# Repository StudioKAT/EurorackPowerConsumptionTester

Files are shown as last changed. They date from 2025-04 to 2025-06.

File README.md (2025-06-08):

# Eurorack Power Consumption Tester
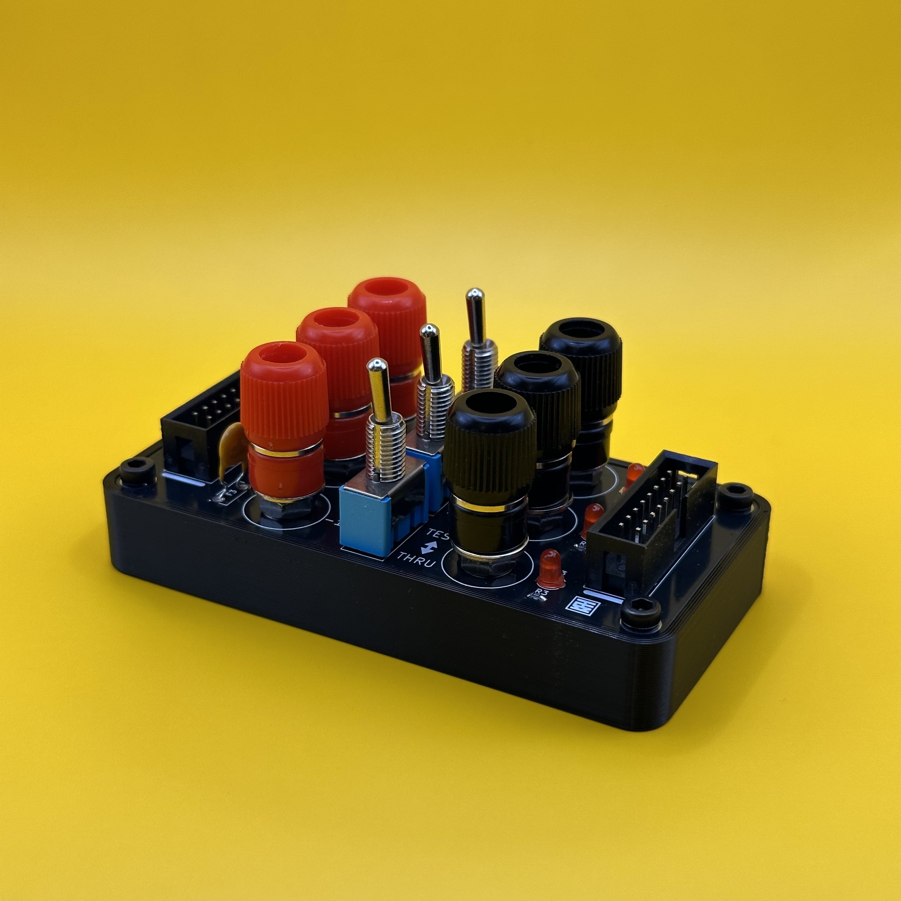
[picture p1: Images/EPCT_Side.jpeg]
Overview


## 概要 / Overview

**Eurorack Power Consumption Tester** は、モジュラーシンセサイザーの消費電力を測定するための治具です。  
デジタルマルチメーター（テスター）と組み合わせて使用し、+5V、+12V、-12Vの各電源レールにおける消費電流の測定が可能です。

**Eurorack Power Consumption Tester** is a utility jig for measuring the power consumption of modular synthesizers.  
Used in combination with a digital multimeter, it allows measurement of current draw on +5V, +12V, and -12V rails.

## 仕様 / Spec
- Format: External testing tool (not a rack-mounted module)  
- Function: Power Consumption Tester Jig
- Current needs: +12V: 0mA, -12V: 0mA (Passive)
- Width: 0 HP
- Depth: 10mm

## 販売 / Sales

現在販売予定はありません。

## ライセンス / License

この作品は [Creative Commons 表示 - 継承 4.0 国際 (CC BY-SA 4.0)](https://creativecommons.org/licenses/by-sa/4.0/deed.ja) の下でライセンスされています。  
This work is licensed under the [Creative Commons Attribution-ShareAlike 4.0 International License](https://creativecommons.org/licenses/by-sa/4.0/).

## クレジット / Credits

- Designed by : StudioKAT
- Website : https://www.studiokat.jp/
- GitHub : https://github.com/StudioKAT
- X(Twitter) : https://x.com/StudioKAT_synth
- Instagram : https://www.instagram.com/studiokat_modular/

## 更新履歴 / Changelog

- `2025-04-24` v1.0 Released version 1.0

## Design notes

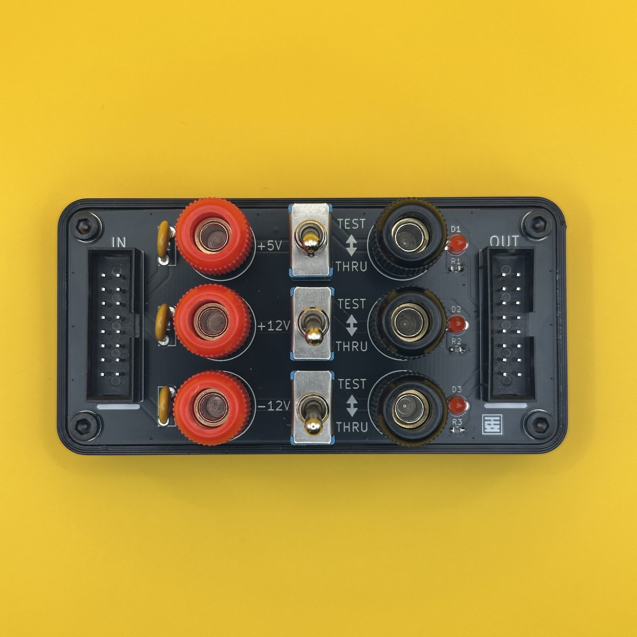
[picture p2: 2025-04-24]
Images/EPCT_Top.jpeg

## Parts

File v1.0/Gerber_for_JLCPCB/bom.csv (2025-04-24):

Designator | Footprint | Quantity | Value | LCSC Part #
D1, D2, D3 | LED_D3.0mm | 3 | LED
F1, F2, F3 | Fuse_Bourns_MF-RG300 | 3 | MF-R050
J1 | BoxHeader_2x08_2.54mm_Europower | 1 | IN
J2 | BoxHeader_2x08_2.54mm_Europower | 1 | OUT
R1 | 0603 | 1 | 1K
R2, R3 | 0603 | 2 | 2.2K
SW1, SW2, SW3 | SPDT | 3 | SW_SPDT

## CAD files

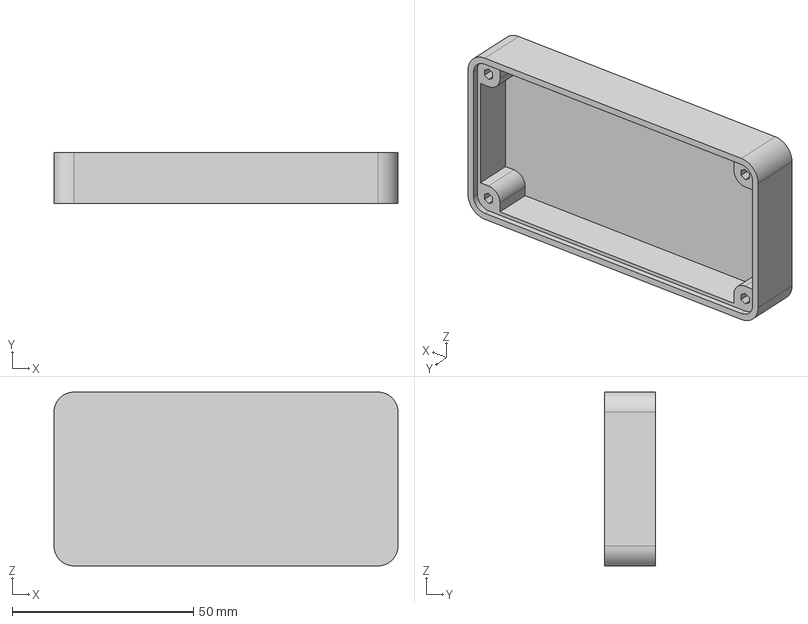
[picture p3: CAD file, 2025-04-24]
v1.0/3DPrint/Eurorack Power Consumption Tester Holder v2.step
95.0 x 14.2 x 48.0 mm

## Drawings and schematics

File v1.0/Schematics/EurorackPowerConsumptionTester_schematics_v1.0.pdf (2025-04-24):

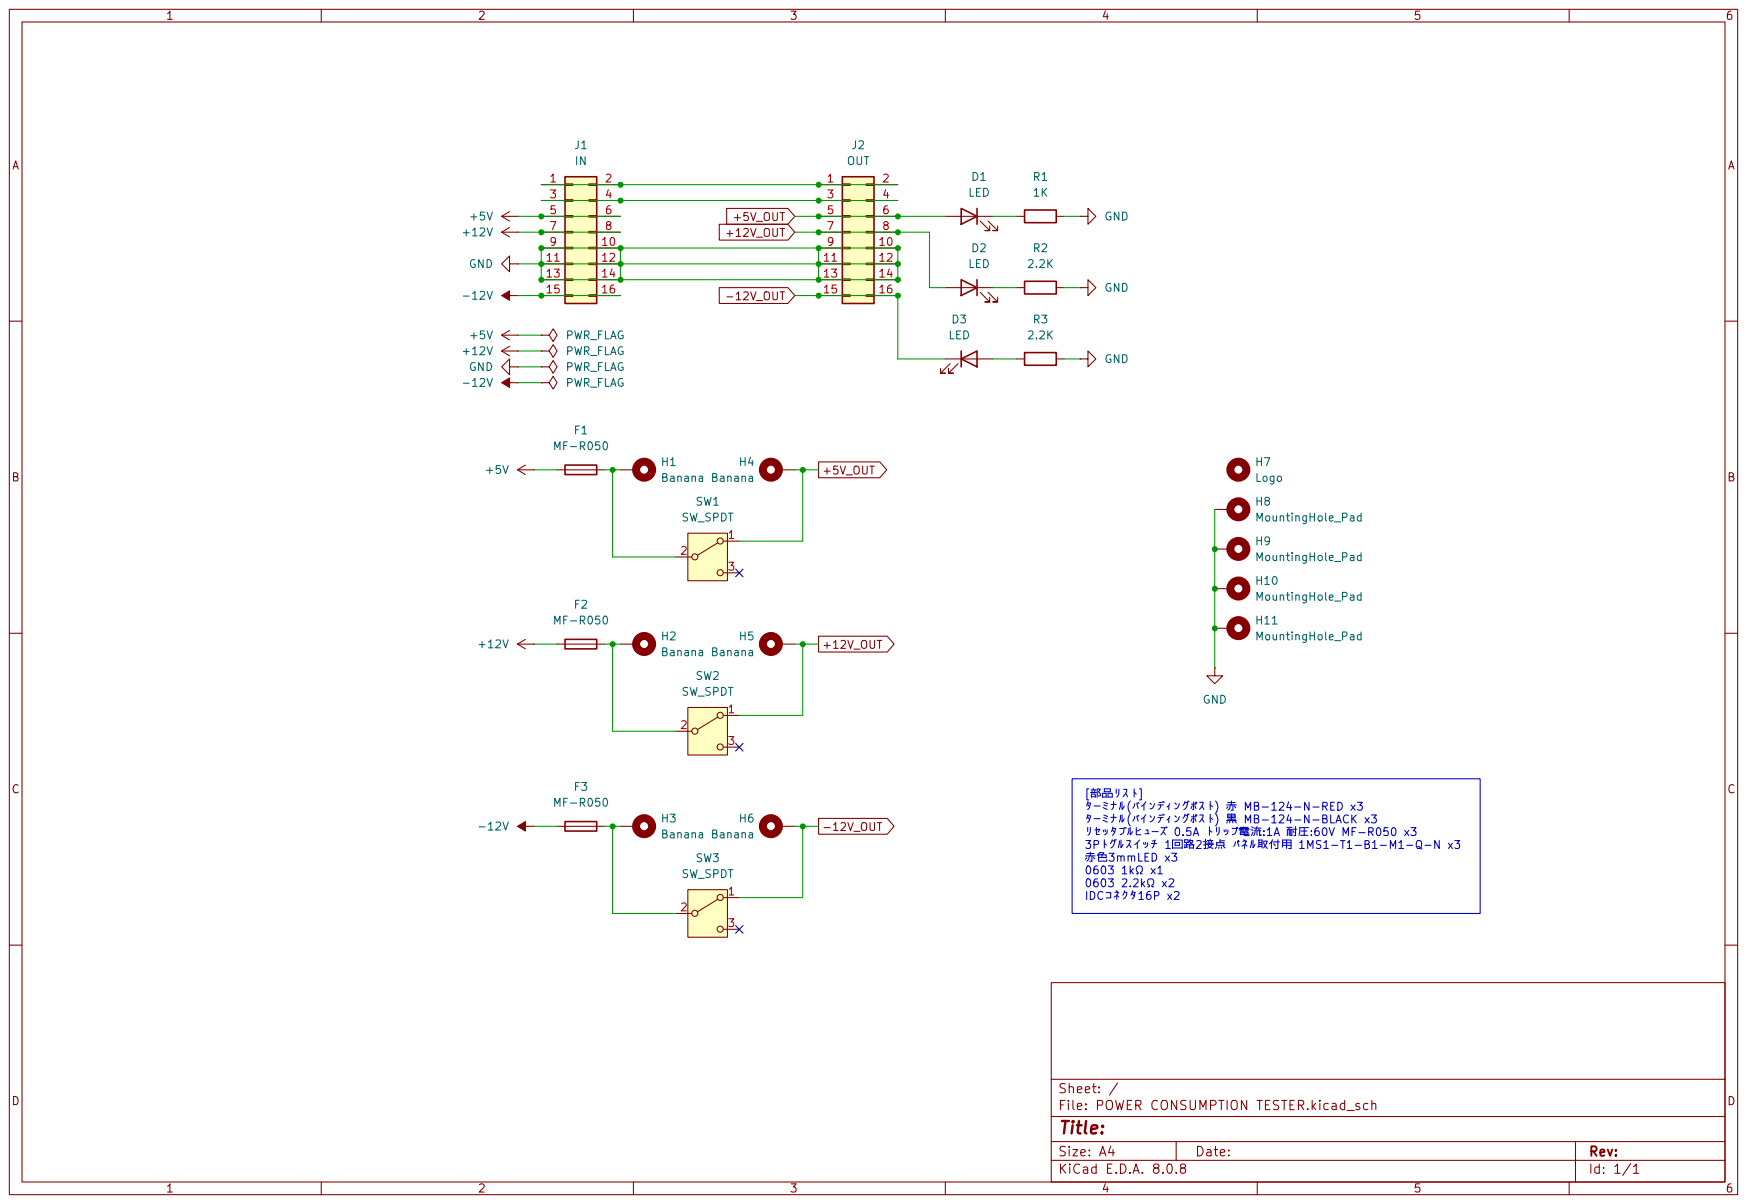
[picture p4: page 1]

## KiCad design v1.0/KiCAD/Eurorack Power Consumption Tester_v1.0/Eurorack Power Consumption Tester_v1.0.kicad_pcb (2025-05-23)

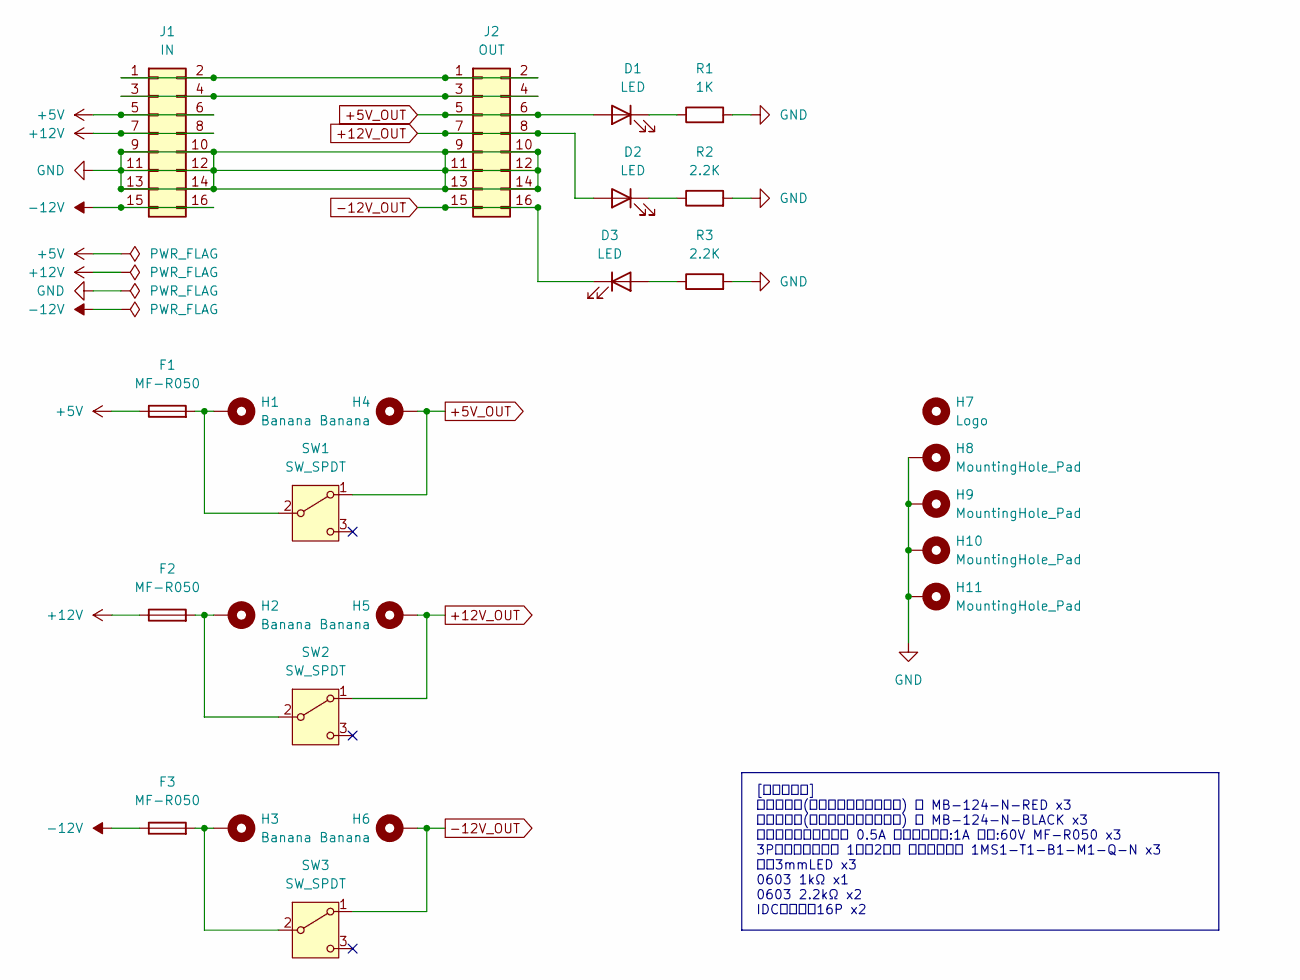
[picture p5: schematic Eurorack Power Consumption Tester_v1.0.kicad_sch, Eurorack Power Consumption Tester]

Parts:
D1, D2, D3: LED; LED_D3.0mm
F1, F2, F3: MF-R050; Fuse_Bourns_MF-RG300
H1, H2, H3, H4, H5, H6: Banana; MountingHole_4.3mm_M4_DIN965_Pad
H7: Logo; StudioKAT_logo
H8, H9, H10, H11: MountingHole_Pad; MountingHole_3.2mm_M3_DIN965_Pad
J1: IN; BoxHeader_2x08_2.54mm_Europower
J2: OUT; BoxHeader_2x08_2.54mm_Europower
R1: 1K; R_0603_1608Metric_Pad0.98x0.95mm_HandSolder
R2, R3: 2.2K; R_0603_1608Metric_Pad0.98x0.95mm_HandSolder
SW1, SW2, SW3: SW_SPDT; SPDT

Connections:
+5V: F1.1, J1.5, J1.6
+5V_OUT: D1.2 (A), H4.1, J2.5, J2.6, SW1.1 (A)
+12V: F2.1, J1.7, J1.8
+12V_OUT: D2.2 (A), H5.1, J2.7, J2.8, SW2.1 (A)
-12V: F3.1, J1.15, J1.16
-12V_OUT: D3.1 (K), H6.1, J2.15, J2.16, SW3.1 (A)
GND: H8.1, H9.1, H10.1, H11.1, J1.9, J1.10, J1.11, J1.12, J1.13, J1.14, J2.9, J2.10, J2.11, J2.12, J2.13, J2.14, R1.2, R2.2, R3.2
unnamed: D1.1 (K), R1.1
unnamed: D2.1 (K), R2.1
unnamed: D3.2 (A), R3.1
unnamed: J1.1, J1.2, J2.1, J2.2
unnamed: J1.3, J1.4, J2.3, J2.4
unnamed: F1.2, H1.1, SW1.2 (B)
unnamed: F2.2, H2.1, SW2.2 (B)
unnamed: F3.2, H3.1, SW3.2 (B)

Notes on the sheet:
[部品リスト] ターミナル(バインディングポスト) 赤 MB-124-N-RED x3 ターミナル(バインディングポスト) 黒 MB-124-N-BLACK x3 リセッタブルヒューズ 0.5A トリップ電流:1A 耐圧:60V MF-R050 x3 3Pトグルスイッチ 1回路2接点 パネル取付用 1MS1-T1-B1-M1-Q-N x3 赤色3mmLED x3 0603 1kΩ x1 0603 2.2kΩ x2 IDCコネクタ16P x2

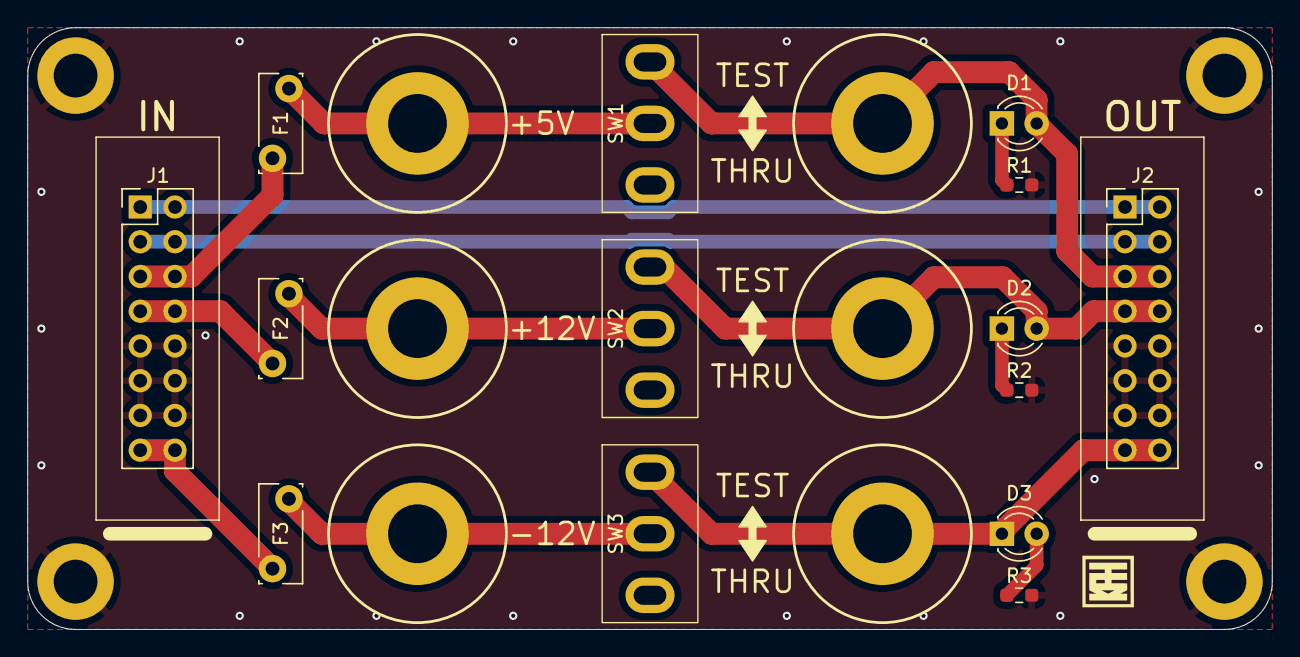
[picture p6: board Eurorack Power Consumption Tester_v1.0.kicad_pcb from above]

Board: 2 copper layers, 91.0 x 44.0 mm, 25 parts (0 on the bottom side), 15 nets.

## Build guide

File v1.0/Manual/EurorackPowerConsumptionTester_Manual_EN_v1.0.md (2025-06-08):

# Eurorack Power Consumption Tester Manual (English)
EPCT_Image

## Overview

**Eurorack Power Consumption Tester** is a utility jig for measuring the power consumption of modular synthesizers.  
Used in combination with a digital multimeter, it allows measurement of current draw on +5V, +12V, and -12V rails.

---

## Specifications

- **Format**: External testing tool (not a rack-mounted module)  
- **Width**: 0 HP  
- **Depth**: 10 mm  
- **Power Draw**: +12V: 0mA / -12V: 0mA (Passive)

---

## Parts List

- [Red Binding Post MB-124-N-RED](https://akizukidenshi.com/catalog/g/g114241/) ×3  
- [Black Binding Post MB-124-N-BLACK](https://akizukidenshi.com/catalog/g/g114242) ×3  
- [Resettable Fuse 0.5A (trip: 1A, 60V) MF-R050](https://akizukidenshi.com/catalog/g/g112628/) ×3  
- [3P Toggle Switch (SPDT) for panel mount](https://akizukidenshi.com/catalog/g/g103774/) ×3  
- [3mm Red LED OSR5JA3Z74A (625nm, 70°)](https://akizukidenshi.com/catalog/g/g111577/) ×3  
- [IDC Box Header 16P (2×8)](https://ja.aliexpress.com/item/1005004266492521.html) ×2  
- Chip Resistor 0603 1kΩ ×1  
- Chip Resistor 0603 2.2kΩ ×2

### Additional Required Tools

- Banana cables ×2  
- Digital multimeter ×1  
- 16P-16P IDC flat cable ×1  
- 16P-10P IDC flat cable ×1

---

## Assembly Tips

- Start with low-profile components (e.g., resistors).  
- The square pad of the LED indicates the cathode (negative).  
- When tightening the binding post nut, be careful not to scratch the solder mask, as this could short to GND.

---

## Usage Instructions

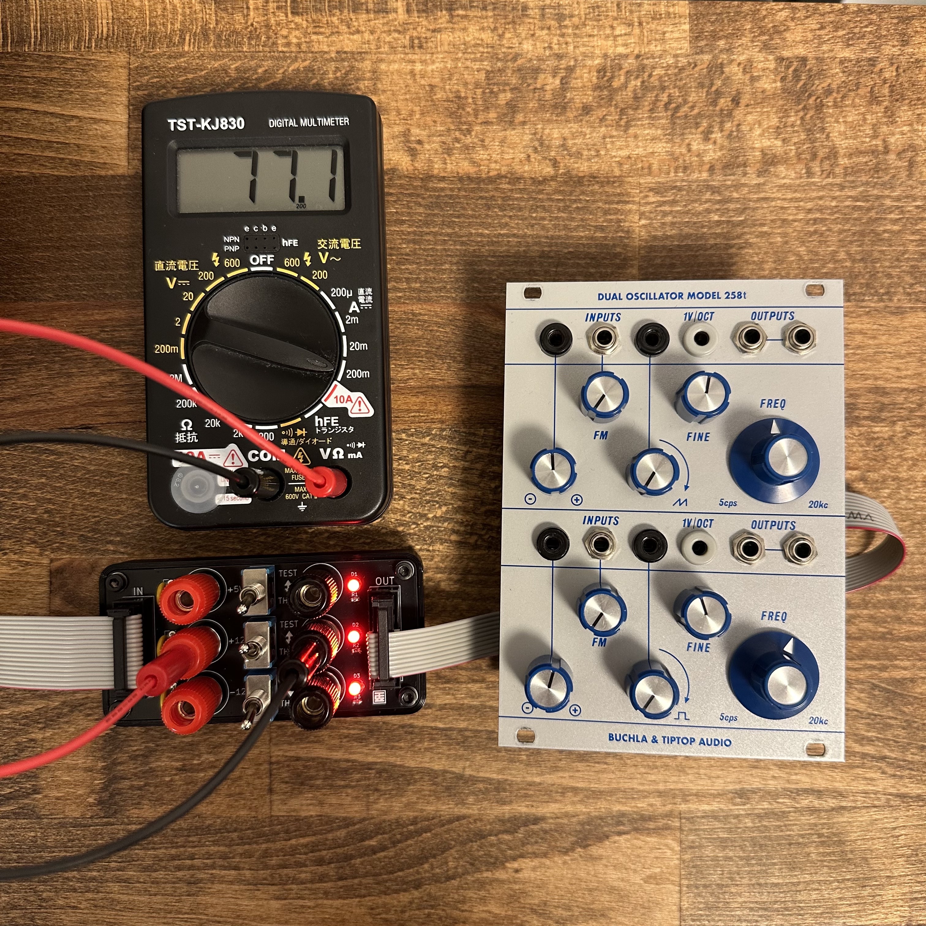
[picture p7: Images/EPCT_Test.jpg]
Measurement


1. Ensure your Eurorack power supply is **OFF**.  
2. Connect the power supply and the tester’s **IN** header using a 16P-16P IDC cable.  
3. Set all three switches (+5V, +12V, -12V) to the **THRU** position.  
4. Connect the tester’s **OUT** to the test module via a 16P-10P cable.  
5. Power on the system. The LEDs on the tester should light up.  
6. Connect the tester’s terminals to a multimeter using banana cables, and set the multimeter to **DC current mode**.  
7. Flip each switch to the **TEST** position to route current through the multimeter and measure consumption.  
8. Apply full load to the module and record current readings.

> ⚠ **Warning**: Do **not** plug/unplug cables while power is on.  
> The designer accepts **no liability** for any damage caused by misuse of this tool.

---

## License

This work is licensed under a [Creative Commons Attribution-ShareAlike 4.0 International License (CC BY-SA 4.0)](https://creativecommons.org/licenses/by-sa/4.0/).

---

## Credits

- **Designed by**: StudioKAT  
- **Website**: [https://www.studiokat.jp/](https://www.studiokat.jp/)  
- **GitHub**: [https://github.com/StudioKAT](https://github.com/StudioKAT)  
- **X (Twitter)**: [https://x.com/StudioKAT_synth](https://x.com/StudioKAT_synth)  
- **Instagram**: [https://www.instagram.com/studiokat_modular/](https://www.instagram.com/studiokat_modular/)

---

## Changelog

- `2025-04-24`: v1.0 Released

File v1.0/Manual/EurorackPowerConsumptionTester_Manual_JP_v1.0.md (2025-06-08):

# Eurorack Power Consumption Tester マニュアル（日本語）
EPCT_Image

## 概要

**Eurorack Power Consumption Tester** は、モジュラーシンセサイザーの消費電力を測定するための治具です。  
デジタルマルチメーター（テスター）と組み合わせて使用し、+5V、+12V、-12Vの各電源レールにおける消費電流の測定が可能です。

---

## 仕様

- **フォーマット**：非モジュール型（外付けツール）  
- **幅**：0 HP（ユーロラックケースにマウント不要）  
- **奥行き**：10 mm  
- **消費電流**：+12V: 0mA / -12V: 0mA（パッシブ）

---

## 部品リスト

- [バインディングポスト（赤）MB-124-N-RED](https://akizukidenshi.com/catalog/g/g114241/) ×3  
- [バインディングポスト（黒）MB-124-N-BLACK](https://akizukidenshi.com/catalog/g/g114242) ×3  
- [リセッタブルヒューズ 0.5A（トリップ電流：1A、耐圧：60V）MF-R050](https://akizukidenshi.com/catalog/g/g112628/) ×3  
- [3Pトグルスイッチ（1回路2接点）パネル取付用](https://akizukidenshi.com/catalog/g/g103774/) ×3  
- [3mm赤色LED OSR5JA3Z74A（625nm、70度）](https://akizukidenshi.com/catalog/g/g111577/) ×3  
- [IDCボックスヘッダー 16P（2×8）](https://ja.aliexpress.com/item/1005004266492521.html) ×2  
- チップ抵抗 0603（1608） 1kΩ ×1  
- チップ抵抗 0603（1608） 2.2kΩ ×2

### その他必要なもの

- バナナケーブル ×2  
- デジタルマルチメーター ×1  
- 16P-16P IDCフラットケーブル ×1  
- 16P-10P IDCフラットケーブル ×1

---

## 組立時の注意点

- 低背部品（チップ抵抗など）から順に取り付けると作業が容易です。  
- LEDは角型パッドがカソード（マイナス極）です。  
- バインディングポストのナットを締める際、レジスト（絶縁層）を傷つけないよう注意してください。  
  レジストが削れて露出するとGNDと短絡し、正しく動作しなくなる可能性があります。

---

## 使用方法

Measurement

1. ケースの電源が**オフ**であることを確認する。  
2. 16P-16Pケーブルで、ケースの電源と測定治具の**IN端子**を接続する。  
3. 全てのスイッチ（+5V, +12V, -12V）を**THRU**側に倒す。  
4. 測定治具の**OUT端子**と検査対象のモジュールを16P-10Pケーブルで接続する。  
5. ケースの電源をオンにし、LEDが点灯することを確認する。  
6. バナナケーブルでテスターと治具の対応端子（+/-）を接続し、テスターを**電流測定モード**に設定する。  
7. 各スイッチを**TEST側**に倒すと、該当電源がテスター経由で供給されるようになり、電流値を測定できる。  
8. モジュールに最大負荷をかけた状態で、消費電流を確認する。

> ⚠ **注意**：電源オン時のケーブルの抜き差しは絶対に行わないでください。  
> 本製品使用中に発生したいかなる損害についても、責任を負いかねます。

---

## ライセンス

この作品は [Creative Commons 表示 - 継承 4.0 国際 (CC BY-SA 4.0)](https://creativecommons.org/licenses/by-sa/4.0/deed.ja) の下でライセンスされています。

---

## クレジット

- **Designed by**：StudioKAT  
- **Website**：[https://www.studiokat.jp/](https://www.studiokat.jp/)  
- **GitHub**：[https://github.com/StudioKAT](https://github.com/StudioKAT)  
- **X（旧Twitter）**：[https://x.com/StudioKAT_synth](https://x.com/StudioKAT_synth)  
- **Instagram**：[https://www.instagram.com/studiokat_modular/](https://www.instagram.com/studiokat_modular/)

---

## 更新履歴

- `2025-04-24`：v1.0 リリース

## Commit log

2025-05-23 KiCADプロジェクト追加
    [Eurorack Power Consumption Tester Holder v2.step, Eurorack Power Consumption Tester_v1.0.kicad_pcb, Eurorack Power Consumption Tester_v1.0.kicad_sch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]
2025-06-08 ディレクトリ構成変更
2025-06-08 画像リンク切れ修正
